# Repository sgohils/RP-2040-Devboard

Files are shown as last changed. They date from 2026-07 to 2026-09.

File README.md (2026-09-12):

https://macondo.hackclub.com/projects/6156

A custom Rp2040 devboard made with everything it need to function, I will use it for my projects and hope to build cool things with it. I followed the tutorial but added many things on my own. Designed in kicad.

# PCB image in kicad


# 3d render


# Schematic


# Bill of materials
| Type | Part Name / Value | Quantity |
| :--- | :--- | :--- |
| Capacitor | 1uF | 2 |
| Capacitor | 0.1uF | 11 |
| Capacitor | 10uF | 2 |
| Capacitor | 33pF | 2 |
| LED | Standard LED | 2 |
| Connector | USB-C Receptacle (USB 2.0 14P) | 1 |
| Header | 20-Pin Header (1x20, 2.54mm) | 2 |
| Header | 3-Pin Header (1x03, 2.54mm) | 1 |
| Resistor | 5.1kΩ | 2 |
| Resistor | 27Ω | 2 |
| Resistor | 1kΩ | 1 |
| Resistor | 10kΩ | 1 |
| Resistor | 1kΩ | 2 |
| Resistor | 470Ω | 1 |
| Resistor | 4.7kΩ | 2 |
| Switch | Push Button (RUN) | 1 |
| Switch | Push Button (BOOTSEL) | 1 |
| Microcontroller | RP2040 | 1 |
| Voltage Regulator | MCP1700x-330xxTT (3.3V LDO) | 1 |
| Flash Memory | W25Q16JVSS (16 Mbit) | 1 |
| Wireless Module | ESP32-WROOM-32 | 1 |
| Crystal Oscillator | 12 MHz | 1 |

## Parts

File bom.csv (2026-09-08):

Id | Designator | Footprint | Quantity | Designation | Supplier and ref
1 | C1, C10 | C_0402_1005Metric | 2 | 1uF
2 | C2, C3, C4, C5, C6, C7, C8, C9, C11, C12, C17 | C_0402_1005Metric | 11 | 0.1uF
3 | C13, C14 | C_0603_1608Metric | 2 | 10uF
4 | C15, C16 | C_0402_1005Metric | 2 | 33pF
5 | D1, D2 | LED_0603_1608Metric | 2 | LED
6 | J1 | USB_C_Receptacle_HRO_TYPE-C-31-M-12 | 1 | USB_C_Receptacle_USB2.0_14P
7 | J2, J3 | PinHeader_1x20_P2.54mm_Vertical | 2 | Conn_01x20
8 | J4 | PinHeader_1x03_P2.54mm_Vertical | 1 | Conn_01x03
9 | R1, R2 | R_0402_1005Metric | 2 | 5.1K
10 | R3, R4 | R_0402_1005Metric | 2 | 27
11 | R5 | R_0402_1005Metric | 1 | 1K
12 | R6 | R_0402_1005Metric | 1 | 10k
13 | R7, R8 | R_0402_1005Metric | 2 | 1k
14 | R9 | R_0402_1005Metric | 1 | 470
15 | R10, R11 | R_0402_1005Metric | 2 | 4.7k
16 | SW1 | SW_Push_SPST_NO_Alps_SKRK | 1 | RUN Button
17 | SW2 | SW_Push_SPST_NO_Alps_SKRK | 1 | BOOTSEL Button
18 | U1 | QFN-56-1EP_7x7mm_P0.4mm_EP3.2x3.2mm | 1 | RP2040
19 | U2 | SOT-23 | 1 | MCP1700x-330xxTT
20 | U3 | Winbond_USON-8-1EP_3x2mm_P0.5mm_EP0.2x1.6mm | 1 | W25Q16JVSS
21 | U4 | MODULE_ESP32-WROOM-32 | 1 | ESP32-WROOM-32
22 | Y1 | Crystal_SMD_3225-4Pin_3.2x2.5mm_HandSoldering | 1 | 12 MHz

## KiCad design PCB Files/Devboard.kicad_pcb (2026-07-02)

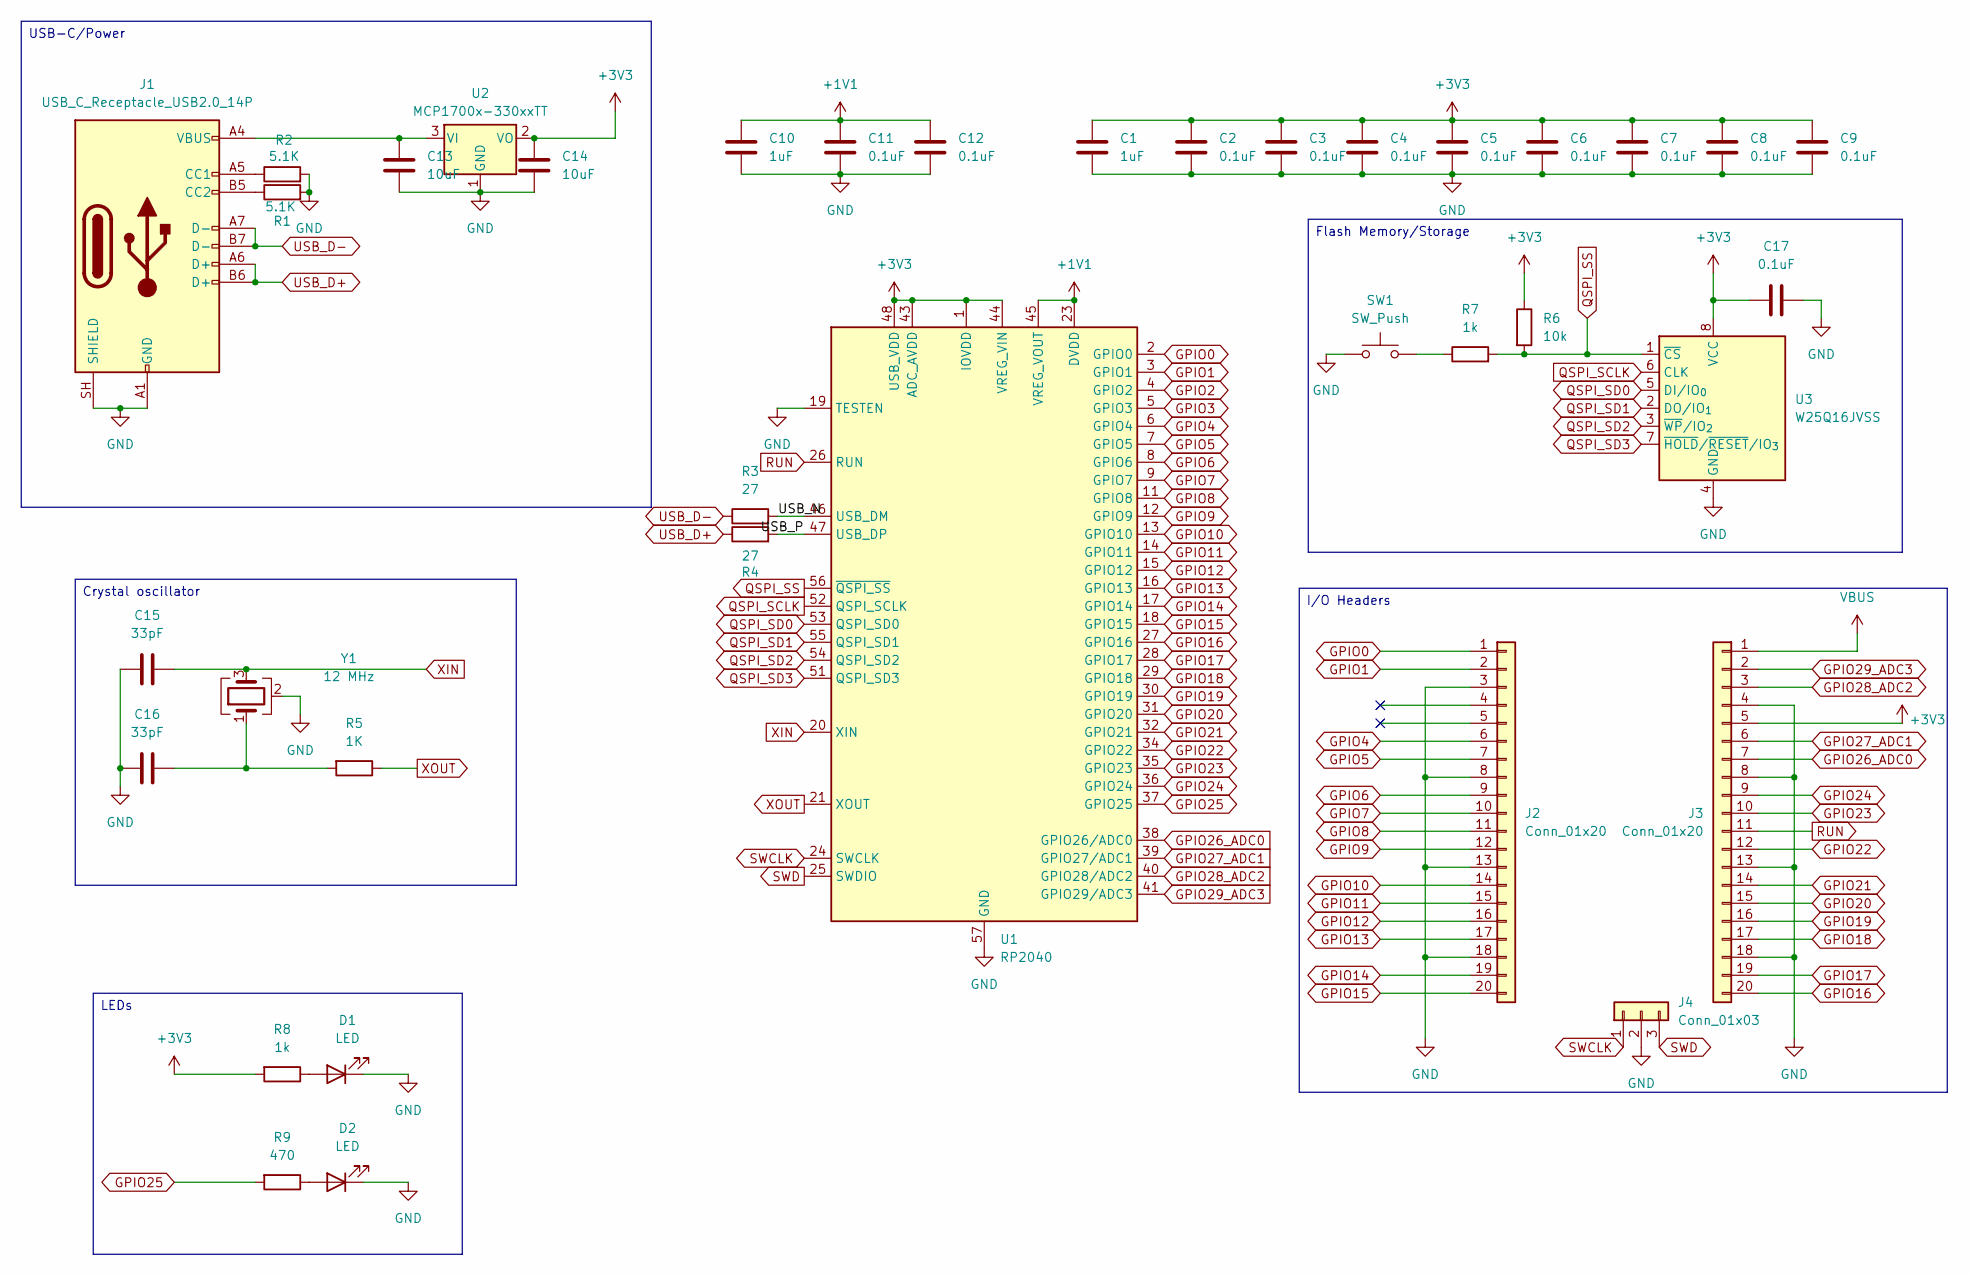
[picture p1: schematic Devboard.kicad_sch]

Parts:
C1, C10: 1uF; C_0402_1005Metric
C2, C3, C4, C5, C6, C7, C8, C9, C11, C12, C17: 0.1uF; C_0402_1005Metric
C13, C14: 10uF; C_0603_1608Metric
C15, C16: 33pF; C_0402_1005Metric
D1, D2: LED; LED_0603_1608Metric
J1: USB_C_Receptacle_USB2.0_14P; USB_C_Receptacle_HRO_TYPE-C-31-M-12
J2, J3: Conn_01x20; PinHeader_1x20_P2.54mm_Vertical
J4: Conn_01x03; PinHeader_1x03_P2.54mm_Vertical
R1, R2: 5.1K; R_0402_1005Metric
R3, R4: 27; R_0402_1005Metric
R5: 1K; R_0402_1005Metric
R6: 10k; R_0402_1005Metric
R7, R8: 1k; R_0402_1005Metric
R9: 470; R_0402_1005Metric
SW1: SW_Push; SW_Push_SPST_NO_Alps_SKRK
U1: RP2040; QFN-56-1EP_7x7mm_P0.4mm_EP3.2x3.2mm
U2: MCP1700x-330xxTT; SOT-23
U3: W25Q16JVSS; Winbond_USON-8-1EP_3x2mm_P0.5mm_EP0.2x1.6mm
Y1: 12 MHz; Crystal_SMD_3225-4Pin_3.2x2.5mm_HandSoldering

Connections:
+1V1: C10.1, C11.1, C12.1, U1.23 (DVDD), U1.45 (VREG_VOUT), U1.50 (DVDD)
+3V3: C1.1, C2.1, C3.1, C4.1, C5.1, C6.1, C7.1, C8.1, C9.1, C14.1, C17.2, J3.5, R6.1, R8.2, U1.1 (IOVDD), U1.10 (IOVDD), U1.22 (IOVDD), U1.33 (IOVDD), U1.42 (IOVDD), U1.43 (ADC_AVDD), U1.44 (VREG_VIN), U1.48 (USB_VDD), U1.49 (IOVDD), U2.2 (VO), U3.8 (VCC); also elsewhere on the board
/USB_N: R3.2, U1.46 (USB_DM)
/USB_P: R4.2, U1.47 (USB_DP)
GND: C1.2, C2.2, C3.2, C4.2, C5.2, C6.2, C7.2, C8.2, C9.2, C10.2, C11.2, C12.2, C13.2, C14.2, C15.1, C16.1, C17.1, D1.1 (K), D2.1 (K), J1.A1 (GND), J1.A12 (GND), J1.B1 (GND), J1.B12 (GND), J1.SH (SHIELD), J2.3, J2.8, J2.13, J2.18, J3.4, J3.8, J3.13, J3.18, J4.2, R1.2, R2.2, SW1.1, U1.19 (TESTEN), U1.57 (GND), U2.1 (GND), U3.4 (GND), Y1.2 (G), Y1.4 (G)
GPIO0: J2.1, U1.2 (GPIO0)
GPIO1: J2.2, U1.3 (GPIO1)
GPIO2: U1.4 (GPIO2); also elsewhere on the board
GPIO3: U1.5 (GPIO3); also elsewhere on the board
GPIO4: J2.6, U1.6 (GPIO4)
GPIO5: J2.7, U1.7 (GPIO5)
GPIO6: J2.9, U1.8 (GPIO6)
GPIO7: J2.10, U1.9 (GPIO7)
GPIO8: J2.11, U1.11 (GPIO8)
GPIO9: J2.12, U1.12 (GPIO9)
GPIO10: J2.14, U1.13 (GPIO10)
GPIO11: J2.15, U1.14 (GPIO11)
GPIO12: J2.16, U1.15 (GPIO12)
GPIO13: J2.17, U1.16 (GPIO13)
GPIO14: J2.19, U1.17 (GPIO14)
GPIO15: J2.20, U1.18 (GPIO15)
GPIO16: J3.20, U1.27 (GPIO16)
GPIO17: J3.19, U1.28 (GPIO17)
GPIO18: J3.17, U1.29 (GPIO18)
GPIO19: J3.16, U1.30 (GPIO19)
GPIO20: J3.15, U1.31 (GPIO20)
GPIO21: J3.14, U1.32 (GPIO21)
GPIO22: J3.12, U1.34 (GPIO22)
GPIO23: J3.10, U1.35 (GPIO23)
GPIO24: J3.9, U1.36 (GPIO24)
GPIO25: R9.2, U1.37 (GPIO25)
GPIO26_ADC0: J3.7, U1.38 (GPIO26/ADC0)
GPIO27_ADC1: J3.6, U1.39 (GPIO27/ADC1)
GPIO28_ADC2: J3.3, U1.40 (GPIO28/ADC2)
GPIO29_ADC3: J3.2, U1.41 (GPIO29/ADC3)
unnamed: C16.2, R5.2, Y1.1
unnamed: D1.2 (A), R8.1
unnamed: D2.2 (A), R9.1
unnamed: J1.A5 (CC1), R2.1
unnamed: J1.B5 (CC2), R1.1
unnamed: R7.1, SW1.2
unnamed: C13.1, J1.A4 (VBUS), J1.A9 (VBUS), J1.B4 (VBUS), J1.B9 (VBUS), U2.3 (VI)
QSPI_SCLK: U1.52 (QSPI_SCLK), U3.6 (CLK)
QSPI_SD0: U1.53 (QSPI_SD0), U3.5 (DI/IO_{0})
QSPI_SD1: U1.55 (QSPI_SD1), U3.2 (DO/IO_{1})
QSPI_SD2: U1.54 (QSPI_SD2), U3.3 (~WP/IO_{2})
QSPI_SD3: U1.51 (QSPI_SD3), U3.7 (~HOLD/~RESET/IO_{3})
QSPI_SS: R6.2, R7.2, U1.56 (~QSPI_SS), U3.1 (~CS)
RUN: J3.11, U1.26 (RUN)
SWCLK: J4.1, U1.24 (SWCLK)
SWD: J4.3, U1.25 (SWDIO)
USB_D+: J1.A6 (D+), J1.B6 (D+), R4.1
USB_D-: J1.A7 (D-), J1.B7 (D-), R3.1
VBUS: J3.1
XIN: C15.2, U1.20 (XIN), Y1.3
XOUT: R5.1, U1.21 (XOUT)

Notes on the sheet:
I/O Headers
LEDs
USB-C/Power
Crystal oscillator
Flash Memory/Storage

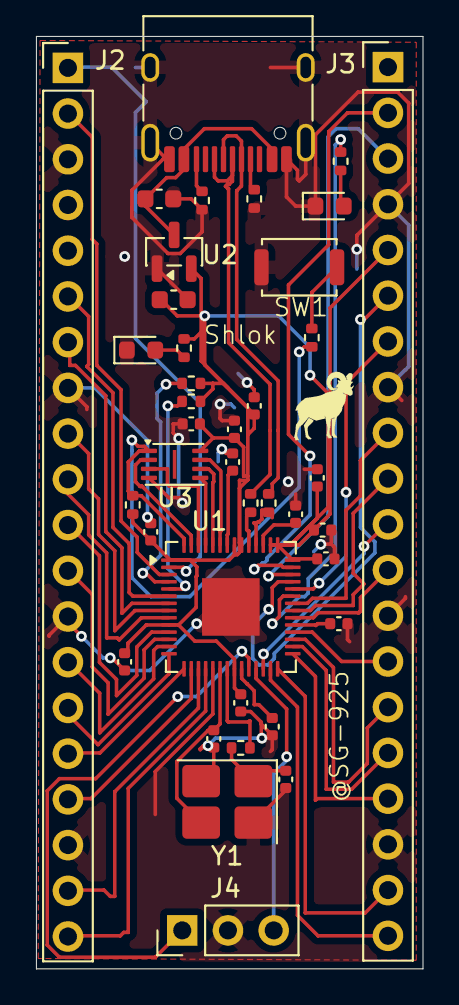
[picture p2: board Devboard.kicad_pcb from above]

Board: 2 copper layers, 21.5 x 51.8 mm, 39 parts (0 on the bottom side), 55 nets.

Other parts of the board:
R10, R11: 4.7k; R_0402_1005Metric

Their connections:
+3V3: R10.2, R11.1; also elsewhere on the board
GPIO2: R10.1; also elsewhere on the board
GPIO3: R11.2; also elsewhere on the board

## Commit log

2026-07-02 Update README with project images and description
    Added images of PCB, 3D render, and schematic in KiCad.
2026-07-02 Add initial KiCad project configuration for Devboard
2026-07-02 Added rest of kicad files
    [Devboard.kicad_pcb, Devboard.kicad_sch]
2026-09-08 Add BOM file with component details
    [bom.csv]
2026-09-12 Add bill of materials to README
    Added a bill of materials section detailing components used.
